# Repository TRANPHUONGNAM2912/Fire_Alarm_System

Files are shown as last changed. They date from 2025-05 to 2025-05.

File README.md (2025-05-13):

# Hệ Thống Báo Cháy Tự Động với Module SIM

Hệ thống báo cháy tự động sử dụng Arduino Nano với các cảm biến phát hiện nhiệt độ, khí gas, lửa và tích hợp module SIM A7680C để gửi cảnh báo qua tin nhắn/cuộc gọi điện thoại.

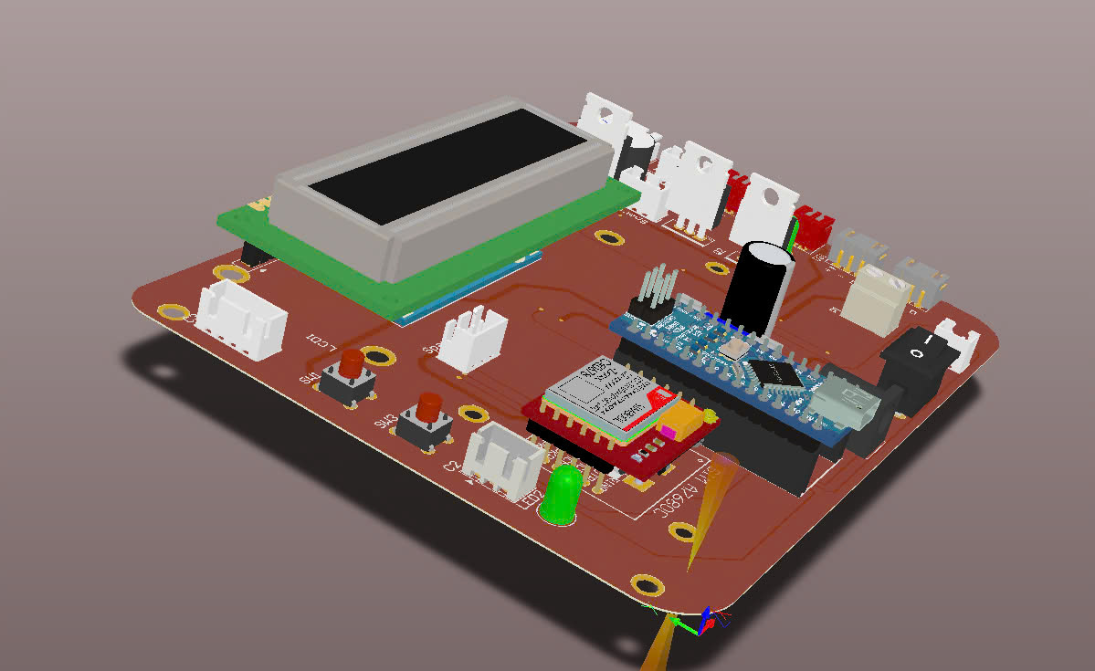
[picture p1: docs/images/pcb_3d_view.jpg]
PCB 3D View


## Tính năng

- **Phát hiện khí gas**: Sử dụng cảm biến MQ2, khi phát hiện nồng độ khí gas vượt ngưỡng, hệ thống sẽ:
  - Bật quạt thông gió
  - Kích hoạt còi báo động
  - Hiển thị cảnh báo trên màn hình LCD
  - Gửi thông báo SMS đến số điện thoại đã cài đặt

- **Phát hiện lửa và nhiệt độ cao**: Sử dụng cảm biến lửa và cảm biến nhiệt độ DS18B20, khi phát hiện lửa hoặc nhiệt độ cao vượt ngưỡng, hệ thống sẽ:
  - Kích hoạt máy bơm nước dập lửa
  - Ngắt nguồn điện tổng thông qua relay
  - Kích hoạt còi báo động
  - Hiển thị cảnh báo trên màn hình LCD
  - Gửi SMS và thực hiện cuộc gọi đến số điện thoại đã cài đặt

- **Hai chế độ hoạt động**:
  - **Chế độ tự động**: Hệ thống tự động phát hiện và phản ứng với các tình huống khẩn cấp
  - **Chế độ thủ công**: Người dùng có thể điều khiển quạt và máy bơm bằng các nút nhấn

- **Cảnh báo từ xa**:
  - Gửi SMS thông báo khi phát hiện sự cố
  - Thực hiện cuộc gọi báo động
  - Cấu hình số điện thoại nhận thông báo qua SMS

## Phần cứng

- **Vi điều khiển**: Arduino Nano
- **Cảm biến**:
  - Cảm biến khí gas MQ2
  - Cảm biến lửa
  - Cảm biến nhiệt độ DS18B20
- **Thiết bị đầu ra**:
  - Màn hình LCD 16x2 với giao tiếp I2C
  - Còi báo động
  - LED báo hiệu
  - Relay điều khiển nguồn điện
  - Quạt thông gió
  - Máy bơm nước
- **Truyền thông**: Module SIM A7680C

## Cấu trúc mã nguồn

- **Thư viện sử dụng**:
  - OneWire: Giao tiếp với cảm biến DS18B20
  - DallasTemperature: Đọc dữ liệu nhiệt độ từ DS18B20
  - Wire: Giao tiếp I2C với LCD
  - LiquidCrystal_I2C: Điều khiển màn hình LCD
  - SoftwareSerial: Giao tiếp với module SIM
  - EEPROM: Lưu trữ số điện thoại

- **Chức năng chính**:
  - Quản lý các cảm biến
  - Hiển thị trạng thái trên LCD
  - Điều khiển thiết bị đầu ra
  - Gửi SMS và thực hiện cuộc gọi thông qua module SIM
  - Chuyển đổi giữa chế độ tự động và thủ công

## Cài đặt

1. Tải mã nguồn từ GitHub
2. Mở file `FireAlarmSystem.ino` trong Arduino IDE
3. Cài đặt các thư viện cần thiết
4. Kết nối phần cứng theo sơ đồ
5. Nạp mã nguồn vào Arduino Nano

## Sử dụng

- **Cấu hình số điện thoại nhận thông báo**:
  - Gửi tin nhắn đến SIM trong mạch với cú pháp: `SDT0123456789` (thay bằng số điện thoại thực)

- **Chuyển đổi chế độ hoạt động**:
  - Nhấn và giữ nút SW1 trong 3 giây để chuyển đổi giữa chế độ tự động và thủ công

- **Chế độ thủ công**:
  - Nhấn SW1 để bật/tắt quạt
  - Nhấn SW2 để bật/tắt máy bơm

## Thiết kế mạch

Mạch được thiết kế bằng phần mềm Altium Designer, bao gồm:
- Mạch nguồn với bộ chuyển đổi LM2596
- Mạch điều khiển dựa trên Arduino Nano
- Module SIM A7680C để gửi tin nhắn và thực hiện cuộc gọi
- Các mạch kết nối với cảm biến và thiết bị đầu ra

## Tài liệu tham khảo

- [Video demo hệ thống báo cháy tự động](https://www.youtube.com/watch?v=evE8AJIoJZU)

## Giấy phép

MIT License

## Tác giả

Trần Phương Nam  
Email: tranphuongnam292003@gmail.com

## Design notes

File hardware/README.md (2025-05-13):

# Thiết kế phần cứng

Thư mục này chứa các tệp thiết kế Altium của mạch điện cho hệ thống báo cháy tự động.

## Linh kiện sử dụng

| STT | Linh kiện | Mô tả | Số lượng |
|-----|---|---|---|
| 1 | Arduino Nano | Vi điều khiển | 1 |
| 2 | MQ2 | Cảm biến khí gas | 1 |
| 3 | DS18B20 | Cảm biến nhiệt độ | 1 |
| 4 | Flame Sensor | Cảm biến lửa | 1 |
| 5 | LCD 16x2 I2C | Màn hình hiển thị | 1 |
| 6 | Module SIM A7680C | Gửi SMS và gọi điện | 1 |
| 7 | LM2596 | Mạch nguồn | 1 |
| 8 | Relay | Ngắt nguồn | 1 |
| 9 | TIP122 | Transistor điều khiển | 3 |
| 10 | Nút nhấn | Điều khiển thủ công | 2 |
| 11 | LED | Đèn báo trạng thái | 4 |
| 12 | Còi | Còi báo động | 1 |
| 13 | Quạt | Thông gió | 1 |
| 14 | Máy bơm nước | Dập lửa | 1 |
| 15 | Các linh kiện thụ động | Điện trở, tụ, diode | - |

## Kết nối

### Cảm biến

- **MQ2** (Cảm biến khí gas):
  - VCC: 5V
  - GND: GND
  - AO: A0 (Arduino)

- **DS18B20** (Cảm biến nhiệt độ):
  - VCC: 5V
  - GND: GND
  - Data: Pin 3 (Arduino)
  - Điện trở pullup 4.7kΩ giữa VCC và Data

- **Flame Sensor** (Cảm biến lửa):
  - VCC: 5V
  - GND: GND
  - DO: Pin 2 (Arduino)

### Thiết bị đầu ra

- **LCD 16x2 I2C**:
  - VCC: 5V
  - GND: GND
  - SDA: A4 (Arduino)
  - SCL: A5 (Arduino)

- **SIM A7680C**:
  - VCC: 5V
  - GND: GND
  - TX: Pin 10 (Arduino)
  - RX: Pin 11 (Arduino)

- **LED**: Pin 12 (Arduino)
- **Còi báo động**: Pin 7 (Arduino)
- **Quạt thông gió**: Pin 5 (Arduino) qua TIP122
- **Bơm nước**: Pin 4 (Arduino) qua TIP122
- **Relay ngắt nguồn**: Pin 6 (Arduino) qua TIP122

### Nút nhấn

- SW1: Pin 9 (Arduino) - Chế độ tự động/thủ công và điều khiển quạt
- SW2: Pin A3 (Arduino) - Điều khiển bơm nước

## Sơ đồ khối

```
+------------+     +-----------------+     +---------------+
| Cảm biến   |     |                 |     | Đầu ra        |
| - Khí gas  |---->|                 |---->| - Quạt        |
| - Lửa      |     |    Arduino      |     | - Bơm nước    |
| - Nhiệt độ |     |     Nano        |     | - Còi báo động|
+------------+     |                 |     | - Relay       |
                   |                 |---->| - LCD         |
+------------+     |                 |     | - LED         |
| Nút nhấn   |---->|                 |     +---------------+
+------------+     +-----------------+
                          |
                          v
                   +-----------------+
                   | Module SIM      |
                   | - Gửi SMS       |
                   | - Gọi điện      |
                   +-----------------+
```

## Thiết kế PCB

Mạch được thiết kế trên phần mềm Altium Designer với các lưu ý sau:

1. Chia thành các khối chức năng riêng biệt: nguồn, xử lý, cảm biến, đầu ra
2. Tách biệt mạch công suất (quạt, bơm, relay) khỏi mạch điều khiển
3. Bố trí các cổng kết nối ở vị trí thuận tiện cho lắp đặt và bảo trì
4. Đặt mạch nguồn gần với đầu vào nguồn để giảm nhiễu
5. Thiết kế mạch 2 lớp giúp tối ưu không gian và giảm nhiễu

## Tệp thiết kế

Trong thư mục `altium_files` có các tệp thiết kế Altium:

- `CanhBaoChay.pdf`: File PDF chứa sơ đồ mạch chi tiết

Ngoài ra, hình ảnh của thiết kế có thể được tìm thấy trong thư mục `docs/images`.

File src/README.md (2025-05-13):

# Mã nguồn hệ thống báo cháy tự động

Thư mục này chứa mã nguồn Arduino cho hệ thống báo cháy tự động với module SIM A7680C.

## Cấu trúc mã nguồn

- `FireAlarmSystem.ino`: File chương trình chính
- `main.h`: File header chứa các hàm xử lý module SIM và các định nghĩa

## Các thư viện sử dụng

```cpp
#include <OneWire.h>           // Giao tiếp với cảm biến DS18B20
#include <DallasTemperature.h> // Đọc dữ liệu từ DS18B20
#include <Wire.h>              // Giao tiếp I2C
#include <LiquidCrystal_I2C.h> // Điều khiển LCD
#include <SoftwareSerial.h>    // Giao tiếp với module SIM
#include <EEPROM.h>            // Lưu trữ số điện thoại
```

## Khai báo chân kết nối

```cpp
int smokeSensorPin = A0;     // Cảm biến khí gas MQ2
int flameSensorPin = 2;      // Cảm biến lửa
int buzzerPin = 7;           // Còi báo động
int ledPin = 12;             // Đèn LED báo động
int fanPin = 5;              // Quạt thông gió
int pumpPin = 4;             // Bơm nước
int relayPin = 6;            // Relay ngắt nguồn
const int sw1 = 9;           // Nút nhấn 1 (chế độ & quạt)
const int sw2 = A3;          // Nút nhấn 2 (bơm)
#define ONE_WIRE_BUS 3       // Cảm biến nhiệt độ DS18B20
#define SERIAL_SIM_TX 11     // TX module SIM
#define SERIAL_SIM_RX 10     // RX module SIM
```

## Cách hoạt động

### Khởi tạo

1. **setup()**: Khởi tạo các chân I/O, màn hình LCD, module SIM và cảm biến
   - Cấu hình chân vào/ra
   - Lấy số điện thoại đã lưu trong EEPROM
   - Khởi động module SIM
   - Gửi SMS thông báo hệ thống đã khởi động

### Vòng lặp chính

2. **loop()**: Vòng lặp chính của chương trình
   - Kiểm tra thông báo từ module SIM
   - Đọc dữ liệu từ các cảm biến
   - Kiểm tra trạng thái nút nhấn để thay đổi chế độ
   - Xử lý theo chế độ tự động hoặc thủ công

### Chế độ tự động

3. **Quy trình xử lý**:
   - Nếu phát hiện khí gas (MQ2):
     * Bật quạt thông gió
     * Kích hoạt còi báo động và LED nhấp nháy
     * Hiển thị cảnh báo trên LCD
     * Gửi SMS thông báo
   
   - Nếu phát hiện lửa và nhiệt độ cao:
     * Bật bơm nước
     * Ngắt relay nguồn
     * Kích hoạt còi báo động và LED nhấp nháy
     * Hiển thị cảnh báo trên LCD
     * Gửi SMS thông báo
     * Thực hiện cuộc gọi sau một khoảng thời gian
   
   - Khi hết sự cố:
     * Tắt các thiết bị sau một khoảng thời gian

### Chế độ thủ công

4. **Điều khiển thủ công**:
   - Nút SW1: Bật/tắt quạt thông gió
   - Nút SW2: Bật/tắt bơm nước
   - Hiển thị trạng thái thiết bị trên LCD

### Chức năng module SIM

5. **Xử lý SMS và cuộc gọi**:
   - Nhận SMS để cấu hình số điện thoại (cú pháp: `SDT0123456789`)
   - Gửi SMS thông báo khi phát hiện sự cố
   - Thực hiện cuộc gọi khi có sự cố nghiêm trọng

## Lưu trữ dữ liệu

- Số điện thoại nhận thông báo được lưu trong EEPROM
- Ngưỡng cảnh báo nhiệt độ và khí gas được cấu hình trong mã nguồn:
  ```cpp
  int smokeThreshold = 100; // Ngưỡng khí gas
  int setteamp = 27;       // Ngưỡng nhiệt độ (°C)
  ```

## Cải tiến tiềm năng

Một số ý tưởng cải tiến cho mã nguồn:

1. Thêm khả năng cấu hình ngưỡng nhiệt độ và khí gas qua SMS
2. Lưu trữ lịch sử sự cố
3. Thêm giao diện web để theo dõi từ xa
4. Tối ưu hóa tiêu thụ năng lượng

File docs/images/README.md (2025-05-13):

# Tài liệu và hình ảnh

Thư mục này chứa các hình ảnh và tài liệu về thiết kế mạch của hệ thống báo cháy tự động.

## Nội dung

- `pcb_3d_view.jpg`: Hình ảnh 3D của PCB
- `pcb_schematic.jpg`: Sơ đồ mạch điện

## Các kết nối chính

### Cảm biến

- **MQ2**: Cảm biến khí gas, kết nối với chân A0 của Arduino
- **DS18B20**: Cảm biến nhiệt độ, kết nối với chân 3 của Arduino
- **Flame Sensor**: Cảm biến lửa, kết nối với chân 2 của Arduino

### Thiết bị đầu ra

- **Quạt thông gió**: Kết nối qua transistor TIP122 với chân 5 của Arduino
- **Bơm nước**: Kết nối qua transistor TIP122 với chân 4 của Arduino
- **Relay ngắt nguồn**: Kết nối qua transistor TIP122 với chân 6 của Arduino
- **Còi báo động**: Kết nối với chân 7 của Arduino
- **LED cảnh báo**: Kết nối với chân 12 của Arduino

### Màn hình

- **LCD I2C 16x2**: Kết nối qua I2C (SDA: A4, SCL: A5)

### Module SIM A7680C

Kết nối SoftwareSerial:
- TX: Chân 11 của Arduino
- RX: Chân 10 của Arduino

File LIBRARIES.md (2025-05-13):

# Thư viện cần thiết

Các thư viện Arduino cần thiết để biên dịch và chạy mã nguồn của hệ thống báo cháy tự động.

## Danh sách thư viện

| Tên thư viện | Phiên bản | Mô tả | Link cài đặt |
|---|---|---|---|
| OneWire | 2.3.7 | Giao tiếp với cảm biến DS18B20 | [Link](https://github.com/PaulStoffregen/OneWire) |
| DallasTemperature | 3.9.0 | Đọc nhiệt độ từ cảm biến DS18B20 | [Link](https://github.com/milesburton/Arduino-Temperature-Control-Library) |
| LiquidCrystal_I2C | 1.1.2 | Điều khiển màn hình LCD qua I2C | [Link](https://github.com/johnrickman/LiquidCrystal_I2C) |
| SoftwareSerial | Built-in | Tạo cổng serial ảo cho module SIM | Có sẵn trong Arduino IDE |
| EEPROM | Built-in | Đọc/ghi dữ liệu vào bộ nhớ EEPROM | Có sẵn trong Arduino IDE |
| Wire | Built-in | Giao tiếp I2C | Có sẵn trong Arduino IDE |

## Cài đặt thư viện

### Sử dụng Arduino Library Manager (Khuyến nghị)

1. Mở Arduino IDE
2. Chọn menu **Sketch > Include Library > Manage Libraries**
3. Trong hộp tìm kiếm, nhập tên thư viện
4. Chọn và cài đặt phiên bản phù hợp

### Cài đặt thủ công

1. Tải thư viện từ link GitHub
2. Giải nén file ZIP
3. Di chuyển thư mục thư viện vào thư mục **libraries** trong thư mục cài đặt Arduino
   - Windows: `Documents/Arduino/libraries/`
   - MacOS: `~/Documents/Arduino/libraries/`
   - Linux: `~/Arduino/libraries/`

## Kiểm tra cài đặt

Sau khi cài đặt các thư viện, bạn có thể kiểm tra bằng cách:

1. Khởi động lại Arduino IDE
2. Chọn menu **File > Examples**
3. Kiểm tra xem các thư viện đã cài đặt có xuất hiện trong danh sách không

## Tương thích

Mã nguồn của dự án đã được kiểm tra và hoạt động tốt với:

- Arduino IDE 1.8.13 hoặc mới hơn
- Arduino Nano (ATmega328)

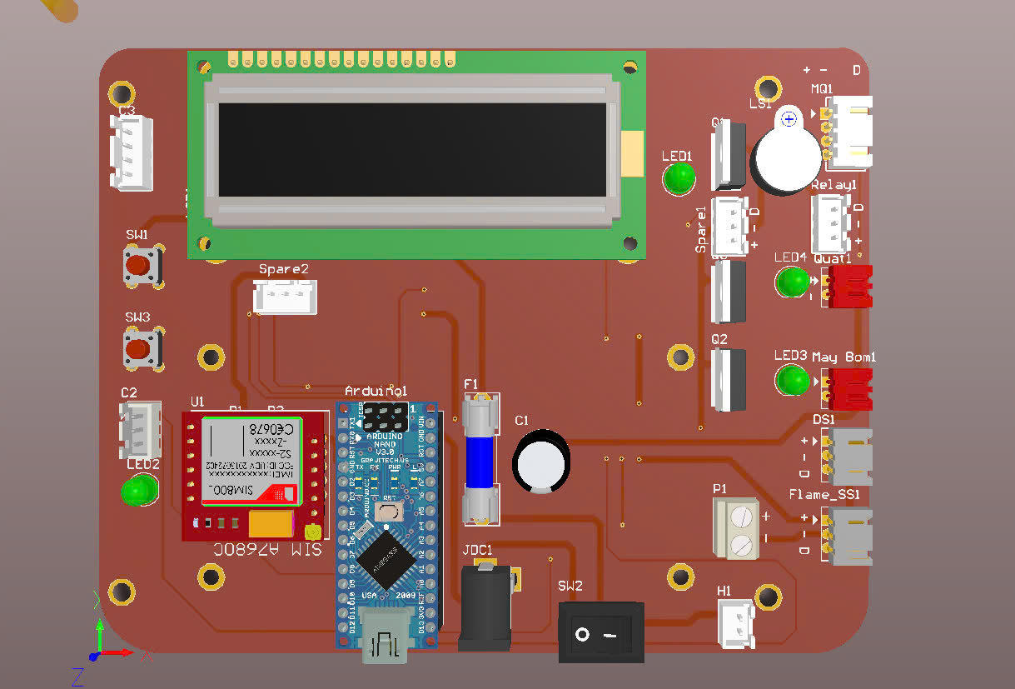
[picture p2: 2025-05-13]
altium/z6060138465834_701cb7d4f500869add291c3dd3a3a177.jpg

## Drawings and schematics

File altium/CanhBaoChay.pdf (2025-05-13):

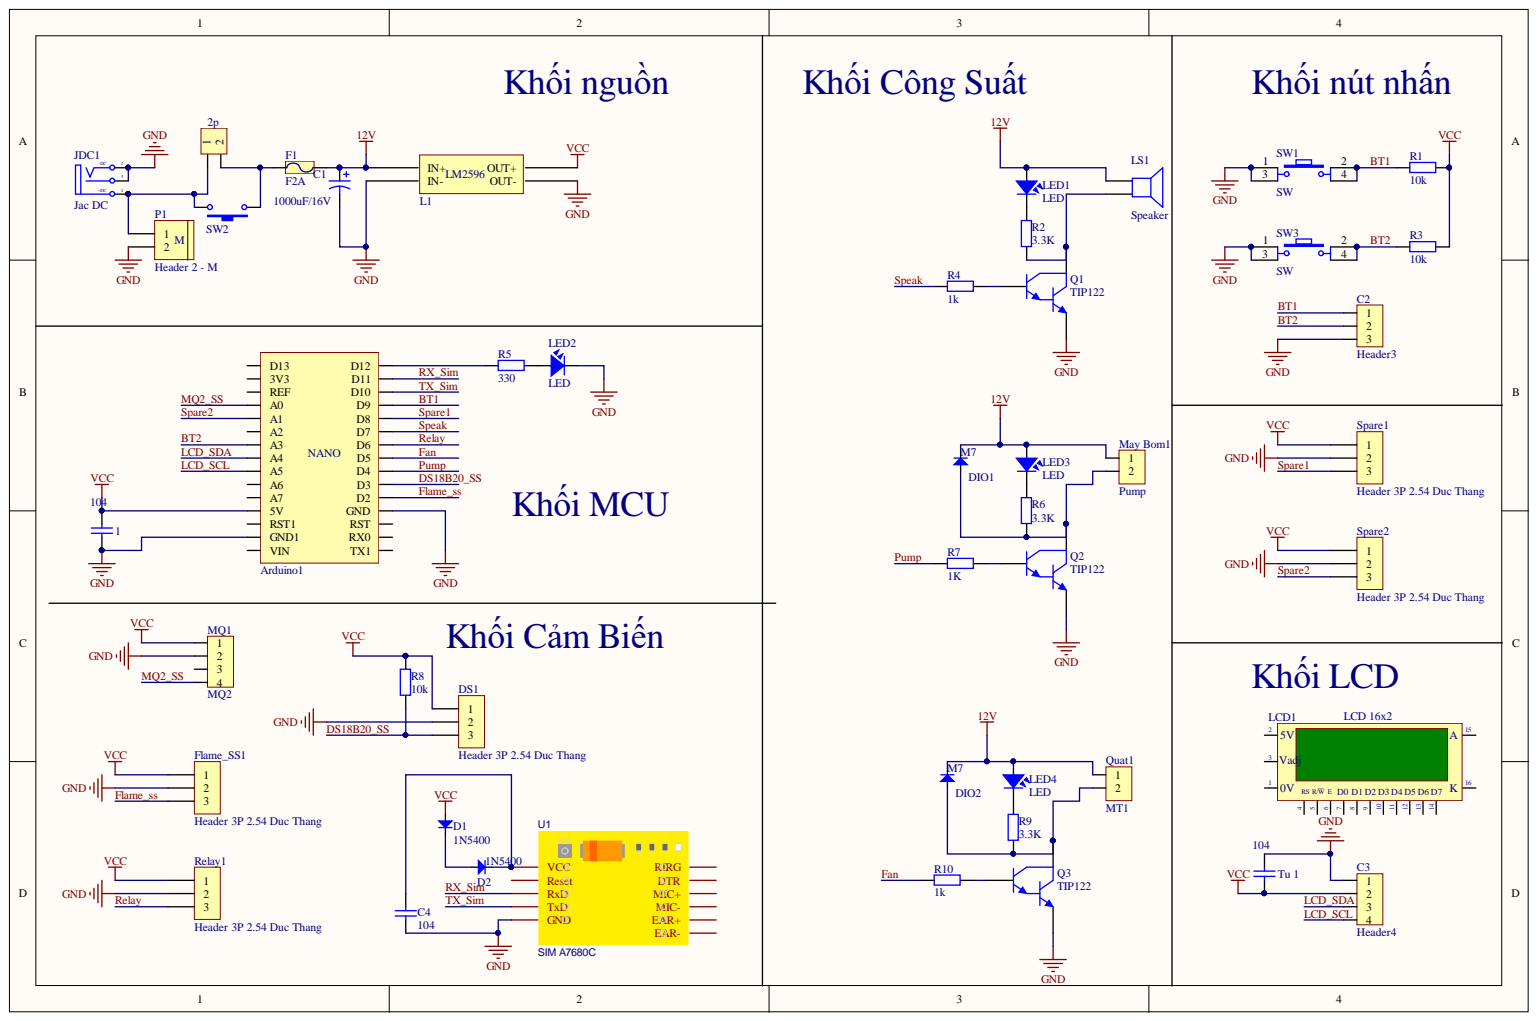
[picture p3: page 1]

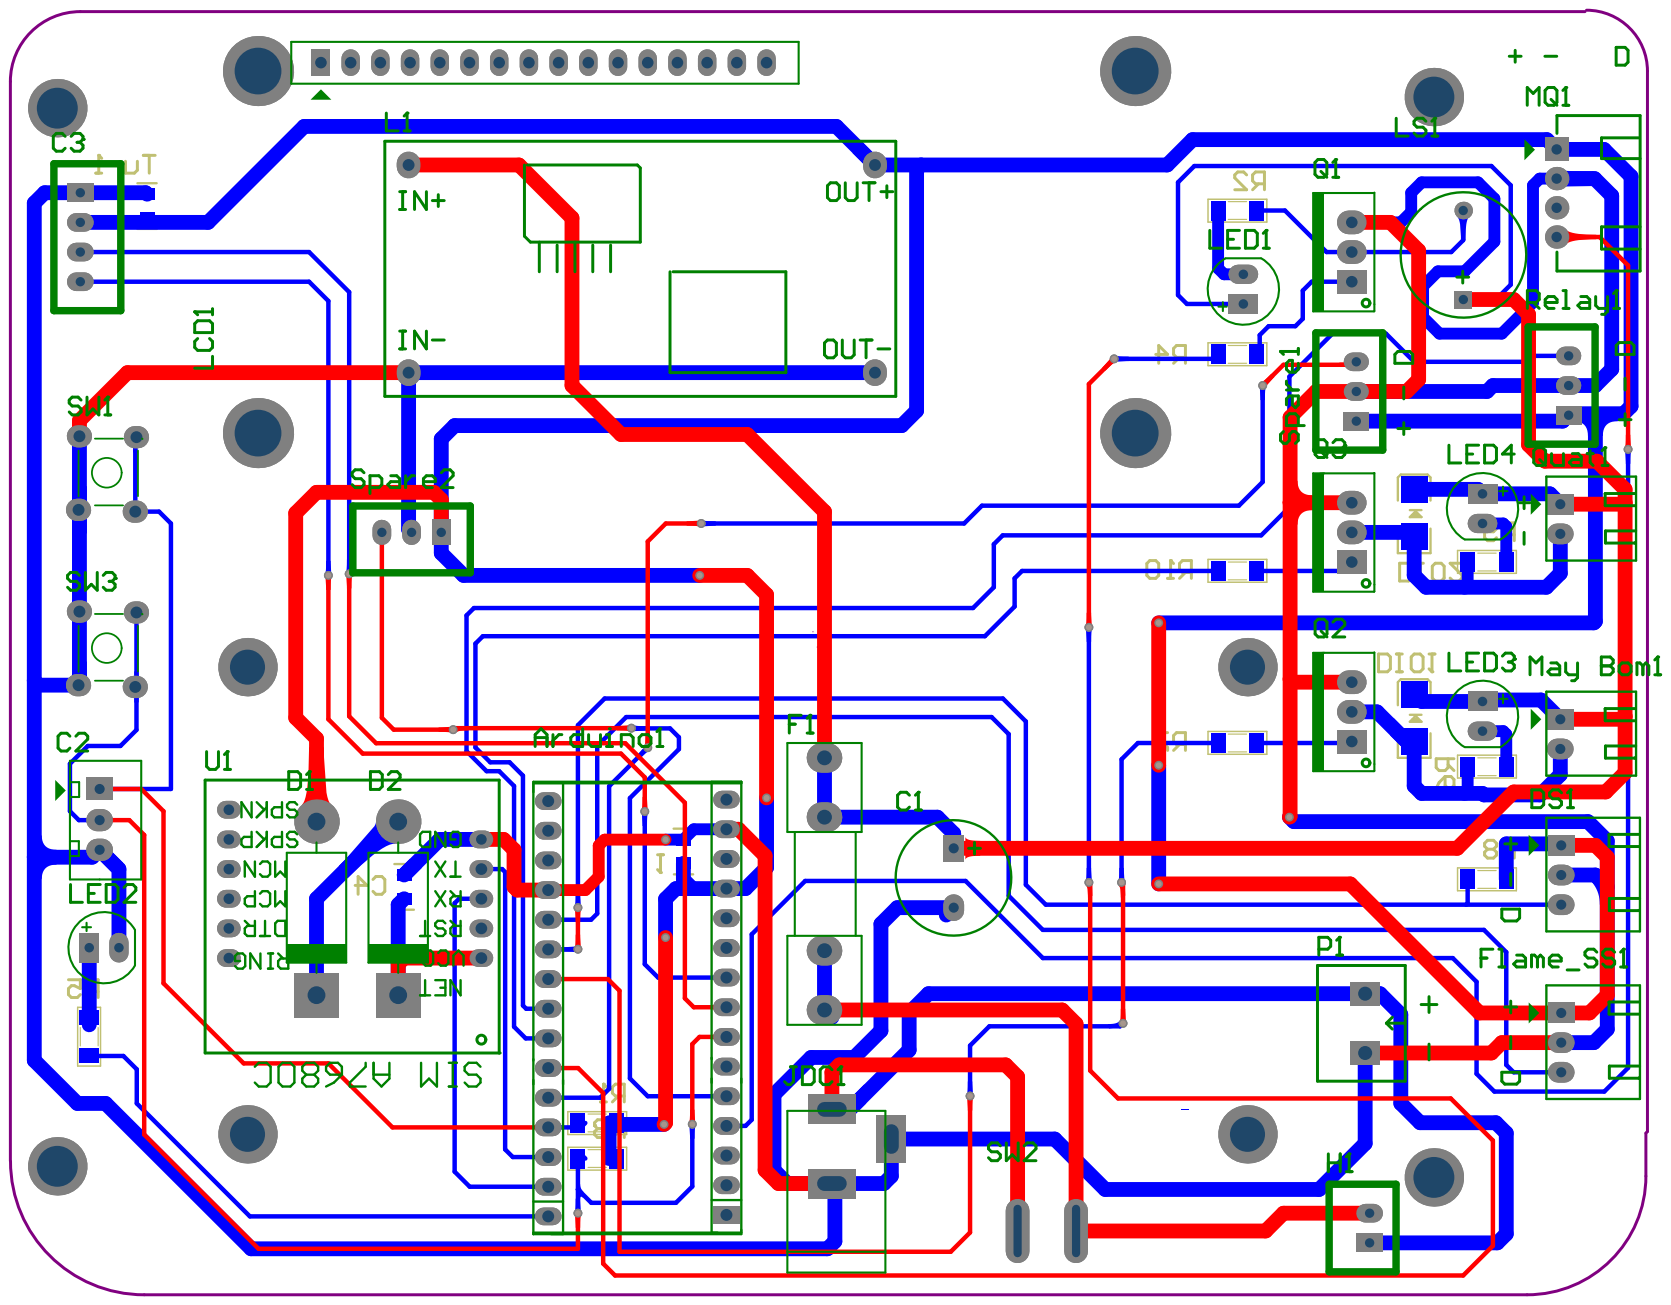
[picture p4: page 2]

Component list | <Parameter Title not found>
Source Data From: | CanhBaoChay.PrjPcb
Project: | | CanhBaoChay.PrjPcb
Variant: | | None
Report Date: | 23/11/2024 | 00:10:02
Print Date: | 23-Nov-24 | 12:10:08 AM
Description | Footprint | Quantitny Name E | Designator #Column Name Error:Manufacture#rCo lumn Name Error:Manufactu#reCor1lu Pmn Name Error:Unit# PColumn Name Error:Manufacture#rCo lumn Name Error:Manufactu#reCor2lu Pmn Name Error:Unit P | | Total Price ($)
Capacitor | C0805 | 3 | 1, C4, Tu 1 | | 0
Arduino NANO | Arduino Nano | 1 | Arduino1 | | 0
Polarized Capacitor (Axial) | C10mm | 1 | C1 | | 0
Header IDC, 3 x 1 Pin Vertical 2.54mm Pitch (Non-Boxed, Male) | Header3 | 1 | C2 | | 0
Header IDC, 4 x 1 Pin Vertical 2.54mm Pitch (Non-Boxed, Male) | XH2.54M-4 | 1 | C3 | | 0
Default Diode | DIO-5A | 2 | D1, D2 | | 0
Default Diode | DIO-SMD-106 | 2 | DIO1, DIO2 | | 0
Cắm | Header 3P DC 2.54 | 2 | DS1, Flame_SS1 | | 0
Fuse | Fuse | 1 | F1 | | 0
Cắm | XH2.54M-2 | 1 | H1 | | 0
Jac DC input | DC-IN | 1 | JDC1 | | 0
| BUCK_LM2596 | 1 | L1 | | 0
| LCD16X2N | 1 | LCD1 | | 0
LED Single colour Green and Red | LED-5 GRe | 4 | LED1, LED2, LED3, LED4 | | 0
Loudspeaker | SPEAKER | 1 | LS1 | | 0
Header IDC, 2 x 1 Pin Vertical 2.54mm Pitch (Non-Boxed, Male) | Header 2P DC 2.54 | 1 | May Bom1 | | 0
Header IDC, 4 x 1 Pin Vertical 2.54mm Pitch (Non-Boxed, Male) | Header 4P DC 2.54 | 1 | MQ1 | | 0
Header, 2-Pin, Medium | Medium - Header 2 | 1 | P1 | | 0
Darlington Silicon Pow er NPN Transistor, 8 Amp, 100 Volts and 65 Watts | QTO-220 | 3 | Q1, Q2, Q3 | | 0
Header IDC, 2 x 1 Pin Vertical 2.54mm Pitch (Non-Boxed, Male) | Header 2P DC 2.54 | 1 | Quat1 | | 0
Resistor SMD 0805 | RES-SMD-1206 | 3 | R1, R3, R8 | | 0
Resistor SMD 0805 | RES-SMD-1206 | 3 | R2, R6, R9 | | 0
Resistor SMD 0805 | RES-SMD-1206 | 3 | R4, R7, R10 | | 0
Resistor SMD 0805 | RES-SMD-1206 | 1 | R5 | | 0
Cắm | XH2.54M-3 | 3 | Relay1, Spare1, Spare2 | | 0
Sw itch button 4 pin | SW4 | 2 | SW1, SW3 | | 0
Nut Nhan 2 Chan SMD 3x6x2.5 | KCD01-11 | 1 | SW2 | | 0
| SIM800L MODULE | 1 | U1 | | 0
| | | | TOTAL PRICE | 0.000

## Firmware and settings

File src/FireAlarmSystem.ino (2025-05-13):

#include <OneWire.h>
#include <DallasTemperature.h>
#include <Wire.h>
#include <LiquidCrystal_I2C.h>
#include "main.h"
LiquidCrystal_I2C lcd(0x27, 16, 2);  
int smokeSensorPin = A0;
int flameSensorPin = 2; 
int buzzerPin = 7;
int ledPin = 12;
int fanPin = 5;
int pumpPin = 4;
int relayPin = 6;
int ledState = LOW;   
const int sw1 = 9;
const int sw2 = A3;
bool prevSw1State = HIGH;
bool prevSw2State = HIGH;
bool sw1State = HIGH;  // Trạng thái của nút sw1
unsigned long sw1PressStartTime = 0;  // Thời điểm bắt đầu giữ nút sw1
const unsigned long holdDuration = 3000;  // Thời gian giữ nút (5 giây)
bool isAutoMode = true;  // Trạng thái chế độ (auto: true, manual: false)

#define ONE_WIRE_BUS 3
OneWire oneWire(ONE_WIRE_BUS);
DallasTemperature sensors(&oneWire);

static bool isNormalScreen = true; 
float temperatureC = 0;
int smokeThreshold = 100; //cài đặt ngưỡng khí gas
int setteamp = 27;//cài đặt thái nhiệt độ
unsigned long previousMillis = 0;
unsigned long previousMillis1 = 0;
unsigned long previousMillis2 = 0;
const long interval = 100;//thời gian led bật tắt
const long duration = 10000;//thời gian các thiết bị hoạt động thêm khi sự cố
bool check = false;//biến kiểm tra xem có sự cố xảy ra không
int check1 = 0;
int check2 = 0;
bool fanState = LOW;
bool pumpState = LOW;
bool fanStatus = false;
bool pumStatus = false;
bool flag=false;
String mumber = "";

void start_up(void)
{
  sim_init();

  sent_sms(mumber, "KHOI DONG HE THONG ");

}
void Task_Sim(void);
void setup() {
  Serial.begin(115200);
  pinMode(sw1, INPUT_PULLUP);
  pinMode(sw2, INPUT_PULLUP);
  pinMode(smokeSensorPin, INPUT);
  pinMode(flameSensorPin, INPUT);
  pinMode(buzzerPin, INPUT);
  pinMode(ledPin, OUTPUT);
  pinMode(fanPin, OUTPUT);
  pinMode(pumpPin, OUTPUT);
  pinMode(relayPin, OUTPUT);
  digitalWrite(relayPin, HIGH);
  lcd.init(); 
  lcd.backlight(); 
  lcd.setCursor(1,0); 
  lcd.print("DANG KHOI DONG"); 
  mumber = "";
  mumber = EEPROM_get(ADD_MUM);
  
  Serial.print("So dien thoai:");
  Serial.println(mumber);

  sim.begin(SIM_BAUD);


  start_up();
  // delay(1000); 
  
  sensors.begin();
}

void loop() {
    Task_Sim();
  int smokeValue = analogRead(smokeSensorPin);//đọc cảm biến khí gas
  int flameValue = digitalRead(flameSensorPin);//đọc cảm biến lửa
  sensors.requestTemperatures();
  int temperatureC = sensors.getTempCByIndex(0);//đọc cảm biến nhiệt độ
// kiểm tra nếu giá trị cảm biến gas đo được lớn hơn giá trị đặt
  // Serial.println(isAutoMode);
  if (digitalRead(sw1) == LOW) {
    if (sw1State == HIGH) {
      // Nếu nút sw1 vừa được nhấn, lưu thời điểm bắt đầu giữ nút
      sw1PressStartTime = millis();
      sw1State = LOW;
    }

    // Kiểm tra thời gian giữ nút
    if (millis() - sw1PressStartTime >= holdDuration) {
      lcd.clear();
      lcd.setCursor(2,0);
      lcd.print("CHANGE MODE ");
      // Nếu nút đã được giữ trong thời gian đủ lâu (5 giây)
      // Kiểm tra chế độ và chuyển đổi
      if (isAutoMode) {
        // Đang ở chế độ auto, chuyển qua chế độ manual
        isAutoMode = false;
        delay(2000);
        
        // Thêm code thực hiện công việc cần thiết khi chuyển sang chế độ manual
      } else {
        // Đang ở chế độ manual, chuyển qua chế độ auto
        isAutoMode = true;
        delay(2000);
        digitalWrite(fanPin, LOW);
        digitalWrite(pumpPin, LOW);
        // Thêm code thực hiện công việc cần thiết khi chuyển sang chế độ auto
      }

      // Reset trạng thái nút sw1 để tránh lặp lại việc chuyển đổi
      sw1State = HIGH;
    }
  } else {
    // Nút sw1 không được nhấn, reset trạng thái nút
    sw1State = HIGH;
  }
  if(isAutoMode==true){
if (smokeValue < smokeThreshold){
  check1=0;
  }
  if (temperatureC < setteamp){
  check2=0;
  }
  
  if (smokeValue > smokeThreshold) {

// đổi trạng thái lcd mỗi 2s
    unsigned long currentMillis1 = millis();
    if (currentMillis1 - previousMillis1 >= 2000) {
      previousMillis1 = currentMillis1; 
      if (isNormalScreen) {
        lcd.clear();
        lcd.setCursor(2,0); 
        lcd.print("TRANG THAI:");
        lcd.setCursor(1,1); 
        lcd.print("PHAT HIEN GAS");
        isNormalScreen = false;
      } else {
        lcd.clear();
        lcd.setCursor(2,0);
        lcd.print("FLAME: ");
        lcd.setCursor(8,0);
        lcd.print("KHONG");
        lcd.setCursor(0,1);
        lcd.print("GAS:");
        lcd.setCursor(4,1);
        lcd.print(smokeValue);
        lcd.setCursor(8,1);
        lcd.print("T: ");
        lcd.setCursor(10,1);
        lcd.print(temperatureC);
        lcd.setCursor(12,1);
        lcd.print("/");
        lcd.setCursor(13,1);
        lcd.print(setteamp);
        isNormalScreen = true;
      }
    }
         check1++;
       if(check1==1){
        sent_sms(mumber, "PHAT HIEN GAS ");
          
      }
      
      
    // bật quạt,buzzer và đổi biến check thành true
    digitalWrite(fanPin, HIGH);
    digitalWrite(buzzerPin, HIGH);
    ledBlink();
    check = true;
  } 
  // kiểm tra xem có lửa và nhiệt độ trên ngưỡng cài đặt không
  else if (flameValue == 0 && temperatureC > setteamp) { 
// chuyển đổi màn hình lcd mỗi 2s
    unsigned long currentMillis1 = millis();
    if (currentMillis1 - previousMillis1 >= 2000) {
      previousMillis1 = currentMillis1; 
      if (isNormalScreen) {
        lcd.clear();
        lcd.setCursor(2,0); 
        lcd.print("TRANG THAI:");
        lcd.setCursor(1,1); 
        lcd.print("PHAT HIEN CHAY");
        isNormalScreen = false;
      } else {
        lcd.clear();
        lcd.setCursor(2,0);
        lcd.print("FLAME: ");
        lcd.setCursor(8,0);
        lcd.print("CO");
        lcd.setCursor(0,1);
        lcd.print("GAS:");
        lcd.setCursor(4,1);
        lcd.print(smokeValue);
        lcd.setCursor(8,1);
        lcd.print("T: ");
        lcd.setCursor(10,1);
        lcd.print(temperatureC);
        lcd.setCursor(12,1);
        lcd.print("/");
        lcd.setCursor(13,1);
        lcd.print(setteamp);
        isNormalScreen = true;
      }
    } 
    // bật bơm,buzzer,relay,đổi biến check thành true
        check2++;
       if(check2==1){
        sent_sms(mumber, "PHAT HIEN CHAY ");
          
      }
       
    digitalWrite(pumpPin, HIGH);
    digitalWrite(buzzerPin, HIGH);
    digitalWrite(relayPin, LOW);
    ledBlink();
    check = true;
  } 
  
  //kiểm tra xem có lửa và nhiệt độ trên ngưỡng cài đặt hoặc khí gas trên ngưỡng cài đặt
  else if (flameValue == 0&& temperatureC < setteamp ) { 
// chuyển màn hình lcd mỗi 2s
    unsigned long currentMillis1 = millis();
    if (currentMillis1 - previousMillis1 >= 2000) {
      previousMillis1 = currentMillis1; 
      if (isNormalScreen) {
        lcd.clear();
        lcd.setCursor(1,0); 
        lcd.print("TRANG THAI");
        lcd.setCursor(1,1); 
        lcd.print("PHAT HIEN LUA");
        isNormalScreen = false;
      } else {
        lcd.clear();
        lcd.setCursor(2,0);
        lcd.print("FLAME: ");
        lcd.setCursor(8,0);
        lcd.print("CO");
        lcd.setCursor(0,1);
        lcd.print("GAS:");
        lcd.setCursor(4,1);
        lcd.print(smokeValue);
        lcd.setCursor(8,1);
        lcd.print("T: ");
        lcd.setCursor(10,1);
        lcd.print(temperatureC);
        lcd.setCursor(12,1);
        lcd.print("/");
        lcd.setCursor(13,1);
        lcd.print(setteamp);
        isNormalScreen = true;
      }
    } 
    // digitalWrite(fanPin, HIGH);
    // digitalWrite(pumpPin, HIGH);
    // digitalWrite(buzzerPin, HIGH);
    // digitalWrite(relayPin, LOW);
    // ledBlink();
    // check = true;
  } else {
    unsigned long currentMillis1 = millis();
    if (currentMillis1 - previousMillis1 >= 2000) {
      previousMillis1 = currentMillis1; 
      if (isNormalScreen) {
        lcd.clear();
        lcd.setCursor(2,0); 
        lcd.print("STATE:");
        lcd.setCursor(9,0); 
        lcd.print("Normal");
        lcd.setCursor(2,1); 
        lcd.print("MODE:");
        lcd.setCursor(8,1); 
        lcd.print("AUTO");
        isNormalScreen = false;
      } else {
        lcd.clear();
        lcd.setCursor(2,0);
        lcd.print("FLAME: ");
        lcd.setCursor(8,0);
        lcd.print("KHONG");
        lcd.setCursor(0,1);
        lcd.print("GAS:");
        lcd.setCursor(4,1);
        lcd.print(smokeValue);
        lcd.setCursor(8,1);
        lcd.print("T: ");
        lcd.setCursor(10,1);
        lcd.print(temperatureC);
        lcd.setCursor(12,1);
        lcd.print("/");
        lcd.setCursor(13,1);
        lcd.print(setteamp);
        isNormalScreen = true;
      } 
    }
    ledOff();
    // bơm,quạt,buzzer bật,relay ngắt thêm 1 khoảng thời gian khi có sự cố
    unsigned long currentMillis2 = millis();
    if (check==true) {
        
      if (currentMillis2 - previousMillis2 >= duration) {
        sim_call(mumber);
        digitalWrite(fanPin, LOW);
        digitalWrite(pumpPin, LOW);
        digitalWrite(buzzerPin, LOW);
        digitalWrite(relayPin, HIGH);
        
        previousMillis2 = currentMillis2;
        check = false; 
    }   
    }
    else{
      previousMillis2 = currentMillis2;
    }
  }

  }
  else{
    
    lcd.setCursor(2,0);
    lcd.print("MODE: ");
    lcd.setCursor(8,0);
    lcd.print("Manual");
    lcd.setCursor(14,0);
    lcd.print(" ");

    lcd.setCursor(0,1); 
    lcd.print("QUAT:");
    lcd.setCursor(5, 1); 
    lcd.print(fanStatus ? "ON " : "OFF");
    lcd.setCursor(8,1); 
    lcd.print(" ");
    lcd.setCursor(9,1); 
    lcd.print("BOM:");
    lcd.setCursor(13, 1); 
    lcd.print(pumStatus ? "ON " : "OFF");
  bool currentSw1State = digitalRead(sw1);
  if (currentSw1State == LOW && prevSw1State == HIGH) {
    // Nếu nút sw1 được nhấn sau khi được nhả ra
    if (fanState == HIGH) {
      // Nếu fanPin đang bật, tắt nó
      digitalWrite(fanPin, LOW);
      fanState = LOW;
      fanStatus = false;
    } else {
      // Nếu fanPin đang tắt, bật nó
      digitalWrite(fanPin, HIGH);
      fanState = HIGH;
      fanStatus = true;
    }
  }
  prevSw1State = currentSw1State; // Lưu trạng thái hiện tại của nút sw1

  // Kiểm tra nút sw2
  bool currentSw2State = digitalRead(sw2);
  if (currentSw2State == LOW && prevSw2State == HIGH) {
    // Nếu nút sw2 được nhấn sau khi được nhả ra
    if (pumpState == HIGH) {
      // Nếu pumpPin đang bật, tắt nó
      digitalWrite(pumpPin, LOW);
      pumpState = LOW;
      pumStatus = false;
    } else {
      // Nếu pumpPin đang tắt, bật nó
      digitalWrite(pumpPin, HIGH);
      pumpState = HIGH;
      pumStatus = true;
    }
  }
  prevSw2State = currentSw2State; // Lưu trạng thái hiện tại của nút sw2
  }
}
// led nhấp nháy mỗi 0.2s
void ledBlink() {
  unsigned long currentMillis = millis();
  if (currentMillis - previousMillis >= interval) {
    previousMillis = currentMillis;
    if (ledState == LOW) {
      ledState = HIGH;
    } else {
      ledState = LOW;
    }
    digitalWrite(ledPin, ledState);
  }
}
// tắt led
void ledOff() {
  digitalWrite(ledPin, LOW);
}

void Task_Sim(void)
{
  if (sim.available())
  {
    String sim_data = sim.readString();
    String messenger = "";
    String telephone_mumber = "";

    if (sim_data[4] == 'M')
    {
      for (int8_t i = 50; i < sim_data.length(); i++)
      {
        messenger += sim_data[i];
      }

      for (uint8_t i = 12; i < sim_data.length() && sim_data[i] != '"'; i++)
      {
        telephone_mumber += sim_data[i];
      }
      Serial.println(sim_data);
      Serial.print("Noi dung tin :");
      Serial.println(messenger);
      Serial.print("So dien thoai den :");
      Serial.println(telephone_mumber);
    }

    if (messenger[0] == 'S' && messenger[1] == 'D' && messenger[2] == 'T')
    {
      mumber = "";
      for (int i = 3; i <= 12; i++)
      {
        mumber += (String)messenger[i];
      }
      Serial.print("So dien thoai cai : ");
      Serial.println(mumber);
      if (mumber.length() == 10)
      {
        EEPROM_put(ADD_MUM, mumber);
        sent_sms("0" + telephone_mumber, "Da luu : " + mumber);
      }
      else sent_sms("0" + telephone_mumber, "Sai cu phap");
    }
    // if (messenger[0] == 'T' && messenger[1] == 'O' && messenger[2] == 'A' && messenger[3] == 'D' && messenger[4] == 'O' )
    // {
    //   read_gps();
    // }
  }
}
